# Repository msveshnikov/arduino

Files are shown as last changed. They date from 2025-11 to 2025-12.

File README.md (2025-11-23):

# First hyper-interactive Robot based on Google Robotics models/gemini-robotics-er-1.5-preview

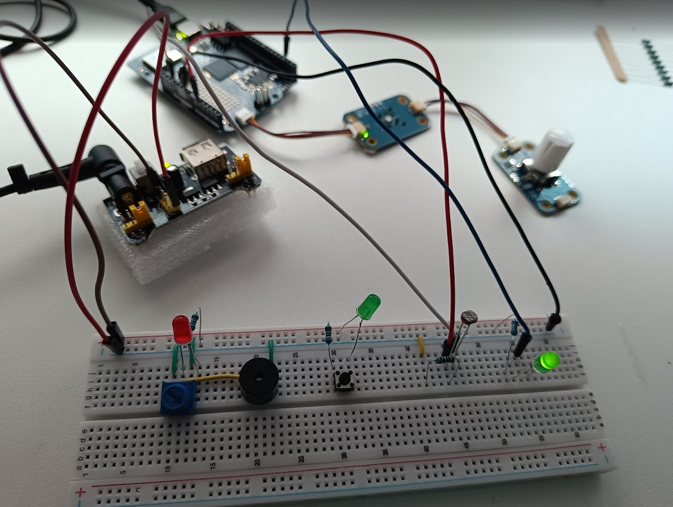
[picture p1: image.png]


## Overview

This project aims to create a highly interactive, autonomous robot utilizing the Google Gemini Robotics ER 1.5 Preview API for decision-making and real-time interaction.

## Current Prototype Specifications

-   **Core Hardware:** Arduino Uno Q (Microcontroller/Motor Control)
-   **Movement:** Two wheels with 360-degree movement capability (differential drive) - **Pins 5 (Left) & 6 (Right)**
-   **Peripherals:** USB-C dongle (USB Camera, USB Speaker, Microphone)
-   **Sensors:** Proximity/Distance Sensor (Analog Pin A0)
-   **Power:** PowerBank 20000 mAh
-   **Software Stack:** Python 3.12, Google Gemini Robotics ER 1.5 Preview API
-   **Connectivity:** WiFi required for API access

**Functionality:** Uses wheels for movement, microphone for audio input, speaker for audio output, and camera for visual input. Capable of making autonomous decisions driven by the AI model.

---

## Design Ideas and Future Considerations

### 1. Hardware Enhancements and Modularity

| Area | Current Status | Proposed Enhancement | Rationale |
| :--- | :--- | :--- | :--- |
| **Microcontroller** | Arduino Uno Q | Transition to Raspberry Pi (e.g., Pi 5 or Zero 2 W) or equivalent SBC | Offload Python processing, improve camera/audio stream handling, and provide local processing capability. |
| **Motor Control** | Integrated with Uno Q | Dedicated Motor Driver Shield (e.g., L298N or specialized drivers) | Better current handling, precision control, and separation of logic/power circuits. |
| **Sensing/Navigation** | USB Camera only | Integrate IMU (Accelerometer/Gyroscope) and Proximity Sensors (Ultrasonic/LiDAR) | Enable robust spatial awareness, obstacle avoidance, and precise movement/pose tracking. |
| **Physical Structure** | N/A (Assumed generic) | Custom 3D Printed Chassis | Modular housing for components, better stability, and improved aesthetics for component housing. |
| **Power Management** | Single PowerBank | Integrated Power Distribution Board (PDB) with voltage regulation | Ensure stable power for SBC, motors, and peripherals; implement low-power warning system. |

### 2. Software Architecture and Code Structure

The project currently uses foundational C code (`music.c`, `starwars.c`, `temp.c`) for low-level tasks, while `main.py` handles high-level logic and API interaction.

-   **Refactor C Code:** Consolidate low-level hardware interaction (motor control, sensor reading) into a dedicated library (e.g., `hardware_interface.c`) callable by Python via `ctypes` or similar bindings.
-   **Python Logic (`main.py`):**
    -   Implement a clear state machine for autonomous behavior (e.g., Idle, Exploring, Interacting, Charging).
    -   Separate API communication handling (API client) from local decision-making (Behavior Tree).
-   **Configuration Management:** Introduce a `config.json` or environment variables for API keys, WiFi settings, and hardware calibration values.

### 3. Interaction and Autonomy Features

-   **Actuation:** Introduce one manipulator arm (e.g., 2-3 DOF) for basic physical object interaction, manipulation, and demonstration.
-   **Multi-Modal Interaction:** Beyond simple command/response, implement context memory for longer, more meaningful conversations that persist across interactions.
-   **Environmental Mapping:** Integrate Simultaneous Localization and Mapping (SLAM) capabilities (if transitioning to an SBC) to allow the robot to navigate and remember its environment structure.
-   **Task Execution:** Design a robust system for handling complex, multi-step instructions (e.g., "Go to the kitchen and report if the coffee machine is on").

### 4. Project Development Setup

-   **Dependency Management:** Utilize a `requirements.txt` file for explicit Python dependency tracking.
-   **Development Environment:** Expand the `.vscode/settings.json` to include linting (e.g., Black, Pylint) and debugging configurations for easier collaboration and development setup.

# Robot Hardware Schema

## Overview

The robot consists of an MCU (Arduino) handling motor control and an MPU (PC/SBC) handling high-level logic, vision, and audio. They are connected via USB (Serial).

## Connection Diagram

```mermaid
graph TD
    subgraph MPU ["MPU (Computer/SBC)"]
        Python[Python Script]
        Webcam[USB Webcam]
        Mic[USB Microphone]
        Speaker[USB Speaker]

        Python <--> Webcam
        Python <--> Mic
        Python <--> Speaker
    end

    subgraph MCU ["MCU (Arduino)"]
        Bridge[Arduino_RouterBridge]
        ServoL["Servo Left (Pin 5)"]
        ServoR["Servo Right (Pin 6)"]
        Sensor["Proximity Sensor (Pin A0)"]

        Bridge --> ServoL
        Bridge --> ServoR
        Bridge --> Sensor
    end

    Python <-->|USB Serial 115200 baud| Bridge
```

## Pinout Configuration

| Component | Arduino Pin | Description |
| :--- | :--- | :--- |
| **Servo Left**  | D5 | Left Wheel (Continuous Rotation)  |
| **Servo Right** | D6 | Right Wheel (Continuous Rotation) |
| **Sensor** | A0 | Proximity/Distance Analog Input |
| **USB** | USB Port | Serial Communication with MPU |

## Power Distribution

-   **Arduino**: Powered via USB or external 7-12V DC jack.
-   **Servos**: **CRITICAL**: Do NOT power servos directly from the Arduino 5V pin. Use an external 5V power supply (e.g., 4xAA battery pack or 5V/2A adapter) for the servos. Connect the external power ground to Arduino GND.

## MPU Requirements

-   **OS**: Linux Debian
-   **Python**: 3.12+
-   **Ports**: 1x USB for Arduino, 1x USB for Webcam, 1x USB for Audio (or 3.5mm jacks).

# TODO

-   [x] use only two motors (servos), reverse one for turning left right
-   [x] get pic from USB and send it to LLM model
-   [x] in prompt ask for json output with fixed schema, allowing speaking and moving (we have no head or arms)
-   [x] speak loudly if returned by model
-   [x] listen to mic and send transcription to LLM model with USB cam picture and proximity sensor data

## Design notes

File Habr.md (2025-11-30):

# Как я собрал робота с характером на базе Gemini API и Arduino Uno Q (и научил его подмигивать)

Привет, Хабр!

Вы когда-нибудь мечтали о роботе, который не просто выполняет команды «едь прямо» или «поверни налево», а может обидеться на вас за глупый вопрос или радостно подмигнуть, увидев кота? Я тоже. И решил, что хватит мечтать — пора собирать.

В этой статье я расскажу, как за пару вечеров собрал "гипер-интерактивного" робота, используя **Arduino Uno Q**, немного Python-магии и **Google Gemini Robotics API**. У него нет рук, нет ног, но есть колеса, матричное лицо и, самое главное, — характер.

<cut/>

## Идея: "Мозг" и "Мышцы"

Главная проблема DIY-роботов — вычислительная мощность. Обычно приходится выбирать между Arduino (хорошо крутит моторами) и Raspberry Pi (умеет думать). Но **Arduino Uno Q** меняет правила игры. Она объединяет в себе и то, и другое:

1.  **MPU (Main Processing Unit)**: Мощный "мозг" на Python, который видит, слышит и общается с LLM (Large Language Model).
2.  **MCU (Microcontroller Unit)**: "Мышцы" (C++), которые дергают сервоприводами, светят светодиодами и следят за датчиками.

## Железо: Из чего же сделаны наши мальчишки?

Сборка получилась максимально доступной (ну, почти):

-   **Arduino Uno Q **: Звезда шоу. Встроенная LED-матрица 12x8 — это киллер-фича для создания "лица" робота без лишних проводов.
-   **Шасси**: Классическая двухколесная платформа (differential drive).
-   **Сервоприводы**: 2 штуки постоянного вращения (Continuous Rotation).
-   **Глаза**: 2 красных светодиода (потому что робот должен выглядеть немного зловеще, правда?). Подключены к пинам 2 и 3.
-   **Сенсоры**: Аналоговый датчик расстояния (чтобы не врезаться в стены, пока мечтает о захвате мира).
-   **Периферия**: USB-вебкамера, микрофон и колонка (подключены к "мозгу").

Схема подключения проста как пробка:

```mermaid
graph TD
    subgraph Arduino Uno Q
        MPU[Python MPU] <-->|Internal Serial| MCU[Arduino MCU]
    end
    MCU --> LeftMotor[Левый мотор D5]
    MCU --> RightMotor[Правый мотор D6]
    MCU --> Eyes[Глаза D2, D3]
    MCU --> Matrix[Матрица 12x8]
```

## Софт: Оживляем Франкенштейна

### 1. Arduino (C++)

Код для микроконтроллера занимается тем, что парсит команды от Python и управляет железом. Самое интересное тут — это **эмоции**.

Благодаря библиотеке `Arduino_LED_Matrix`, мы можем рисовать на встроенной матрице R4. Я определил несколько "кадров" для эмоций:

-   Neutral (Спокойствие)
-   Happy (Счастье)
-   Sad (Грусть)
-   Angry (Гнев — любимая эмоция моего робота)
-   Surprised (Удивление)

Команда от Python приходит в формате: `L90;R90;E1;Y11`.

-   `L/R`: Скорость моторов (90 — стоп).
-   `E`: ID эмоции.
-   `Y`: Состояние глаз (11 — оба горят, 10 — левый горит, и т.д.).

### 2. Python (MPU)

Этот код выполняется на MPU части платы. Мы используем **Google Gemini Robotics ER 1.5 Preview**. Это не просто чат-бот, это мультимодальная модель, которая может "видеть" картинки и понимать контекст.

Самое важное — это **System Prompt**. Мы должны объяснить модели, кто она такая и как управлять своим телом.

```python
self.system_prompt = """
You are a robot assistant with two wheels and NO arms.
You have an LED matrix for a face and two extra LEDs for eyes.
You must respond in valid JSON format ONLY.
The JSON schema is:
{
    "speech": "text to speak",
    "left_motor": int (-100 to 100),
    "right_motor": int (-100 to 100),
    "emotion": "neutral" | "happy" | "sad" | "angry" | "surprised",
    "eyes": {"left": bool, "right": bool}
}
"""
```

Заметьте, мы не пишем `if text == "hello": smile()`. Мы даем модели **полную свободу**. Если она решит, что ваша шутка смешная, она вернет `emotion: "happy"`. Если вы ее оскорбите — `emotion: "angry"` и, возможно, `left_motor: 100` (таранный удар).

## Как это работает в жизни

Цикл работы робота выглядит так:

1.  **Слушаем**: Распознаем речь через `speech_recognition`.
2.  **Смотрим**: Делаем снимок с веб-камеры.
3.  **Думаем**: Отправляем текст + картинку + данные сенсоров в Gemini.
4.  **Действуем**: Получаем JSON, парсим его и шлем команды на Arduino.
5.  **Говорим**: Озвучиваем ответ через `pyttsx3`.

### Пример диалога:

**Я**: "Привет! Как настроение?"
**Робот** (JSON от Gemini):

```json
{
    "speech": "Привет! Системы в норме, настроение боевое.",
    "emotion": "happy",
    "eyes": { "left": true, "right": true },
    "left_motor": 0,
    "right_motor": 0
}
```

_На матрице загорается смайлик, глаза светятся._

**Я**: "Помигай глазами!"
**Робот**:

```json
{
    "speech": "Пожалуйста. Бип-буп.",
    "emotion": "neutral",
    "eyes": {"left": false, "right": true},
    ...
}
```

_Один глаз гаснет, робот подмигивает._

## Грабли, на которые я наступил

1.  **Питание сервоприводов**: Никогда, слышите, НИКОГДА не питайте моторы от 5V пина Arduino. Я поплатился часами отладки "почему оно перезагружается при повороте". Только внешнее питание!
2.  **JSON Hallucinations**: Иногда LLM забывает закрыть скобку или добавляет лишний текст. Пришлось добавить `try-except` и очистку от markdown-тегов.
3.  **Задержки**: Обработка картинки и запрос к API занимают время (1-2 секунды). Для real-time гонок не пойдет, но для вдумчивого собеседника — вполне.

## Итоги

Проект получился живым. Это не просто машинка на радиоуправлении, это сущность, которая _понимает_, что происходит вокруг. Добавление эмоций через LED-матрицу и глаза кардинально меняет восприятие устройства. Оно кажется... живым?

**Что дальше?**

-   Добавление манипулятора (руки!), чтобы он мог не только смотреть, но и трогать.
-   SLAM навигация.

Код проекта открыт (ну, лежит у меня в папке), так что дерзайте! Роботы — это весело. Особенно когда они умеют злиться.

---

_P.S. Если робот начнет просить коды запуска ядерных ракет, я его отключу. Обещаю._

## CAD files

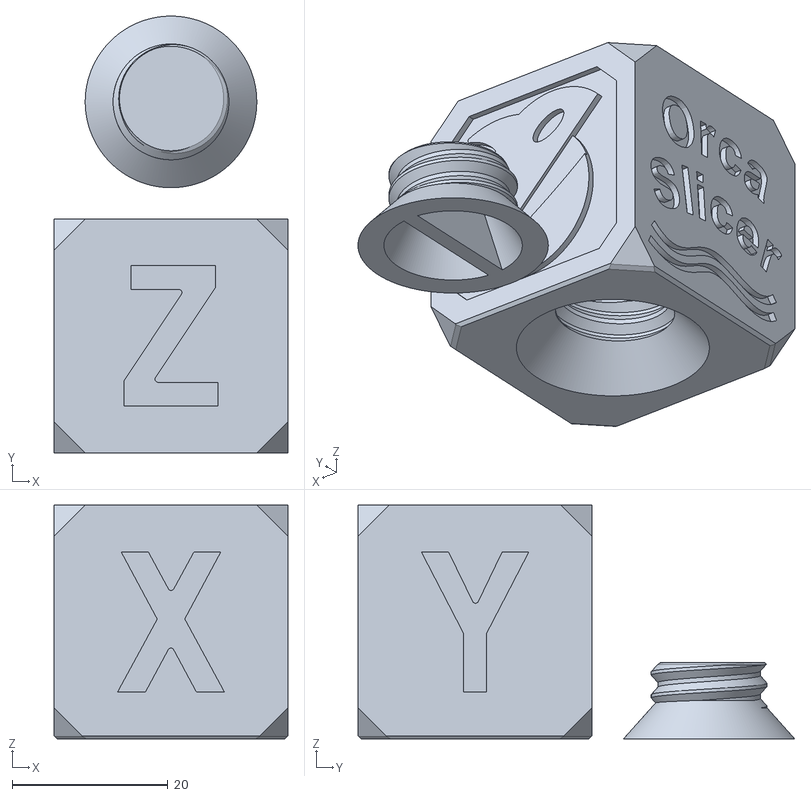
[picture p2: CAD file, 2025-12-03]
3d/OrcaCube.stl
30.0 x 56.0 x 30.0

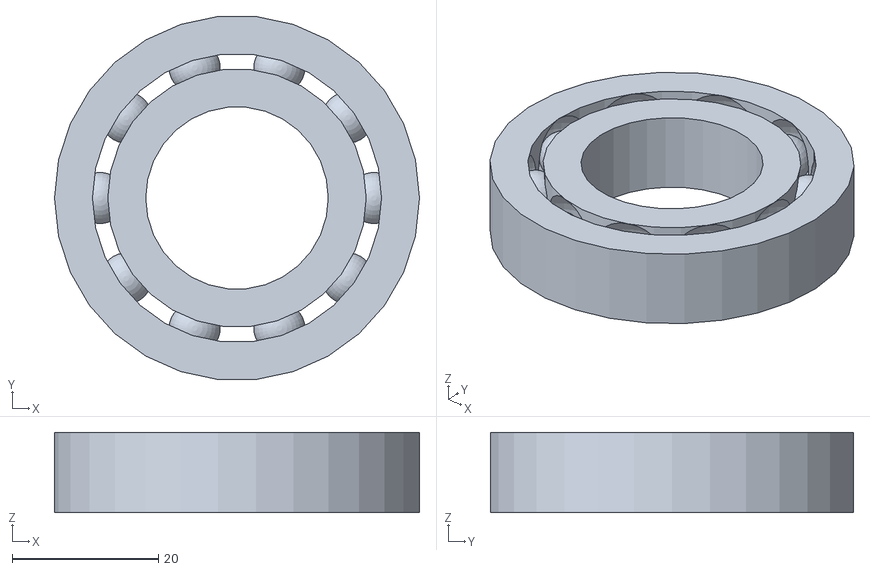
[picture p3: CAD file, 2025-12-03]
3d/bearing.stl
50.0 x 49.7 x 11.0

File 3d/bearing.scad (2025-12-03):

// Title: Подшипник (Print-in-Place Bearing)
// Description: Параметрическая модель шарикового подшипника, предназначенная для 3D-печати как единое целое.
// Author: AI Assistant
// Date: 2023-10-28
// License: MIT

/*
 * =====================================================================
 * Параметры для настройки (Parameters for Customization)
 * =====================================================================
 */

// --- Основные размеры ---
outer_diameter = 50;   // [mm] Внешний диаметр подшипника
inner_diameter = 25;   // [mm] Внутренний диаметр подшипника
height = 11;         // [mm] Высота подшипника

// --- Параметры шариков ---
num_balls = 10;      // Количество шариков
ball_diameter = 7;   // [mm] Диаметр одного шарика

// --- Параметры для печати ---
clearance = 2.1;     // [mm] Зазор между деталями для свободного вращения
$fn = 30;             // Качество модели (количество граней), уменьшено по вашему запросу

/*
 * =====================================================================
 * Модули (Modules)
 * =====================================================================
 */

// Модуль для создания подшипника
module bearing() {
    // Вычисляем радиус, на котором будут располагаться шарики
    path_radius = (outer_diameter + inner_diameter) / 4;

    // Основное тело подшипника в сборе
    union() {
        // Создаем кольца с вырезами под шарики и зазором между собой
        difference() {
            // --- 1. Создаем исходное цельное кольцо ---
            difference() {
                cylinder(d = outer_diameter, h = height, center = true);
                cylinder(d = inner_diameter, h = height + 1, center = true);
            }

            // --- 2. Вырезаем тонкую щель для разделения колец ---
            // Эта операция создает зазор, превращая одно кольцо в два.
            difference() {
                cylinder(d = (path_radius * 2) + clearance, h = height + 1, center = true);
                cylinder(d = (path_radius * 2) - clearance, h = height + 2, center = true);
            }

            // --- 3. Вырезы для шариков (с зазором) ---
            // Делаем вырезы немного больше шариков, чтобы они могли вращаться.
            for (i = [0 : num_balls - 1]) {
                rotate([0, 0, i * 360 / num_balls]) {
                    translate([path_radius, 0, 0]) {
                        sphere(d = ball_diameter + clearance * 2);
                    }
                }
            }
        }

        // --- 4. Создаем сами шарики ---
        // Шарики размещаются в созданных для них полостях.
        for (i = [0 : num_balls - 1]) {
            rotate([0, 0, i * 360 / num_balls]) {
                translate([path_radius, 0, 0]) {
                    sphere(d = ball_diameter);
                }
            }
        }
    }
}

/*
 * =====================================================================
 * Основной код (Main Code)
 * =====================================================================
 */

bearing();

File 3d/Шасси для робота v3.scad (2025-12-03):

// Title: Robot Assembly (Chassis + 4 Wheels)
// Description: Parametric chassis with 4 wheels positioned 2mm outward.
// Combined and Modified by: AI Assistant

/*
 * =====================================================================
 * 1. GLOBAL PARAMETERS (Merged)
 * =====================================================================
 */

// --- Chassis Dimensions ---
chassis_length = 240;  // [mm] Y-axis
chassis_width = 120;   // [mm] X-axis
chassis_height = 40;   // [mm] Z-axis
wall_thickness = 3;    // [mm]

// --- Servo Cutouts ---
servo_cutout_width = 24;
servo_cutout_height = 12;
servo_hole_distance = 28;
servo_hole_diameter = 1.5;
servo_pos_from_front = 50; // Distance from servo center to front

// --- Rear Axle Holes ---
rear_hole_diameter = 6;
rear_hole_pos_from_back = 40;

// --- Vertical Positioning ---
cutouts_z_pos = 20; // Height of axles/servos

// --- Chassis Posts ---
post_size = 10;
post_height = 5;

// --- Wheel Parameters ---
wheel_diameter = 60;
wheel_thickness = 5;
wheel_offset = 2; // [mm] Distance from chassis wall to wheel

// --- Tread Parameters ---
tread_grooves = 40;
tread_groove_depth = 1.5;
tread_groove_width = 4;

// --- Wheel Mounting Parameters ---
mount_hole_distance = 32;
mount_hole_diameter = 1.5;
servo_horn_recess_depth = 2.5;
servo_spline_hole_diameter = 6;
servo_horn_hub_diameter = 7;
servo_horn_arm_width = 6;

// --- Quality ---
$fn = 100;

/*
 * =====================================================================
 * 2. MODULE: CHASSIS
 * =====================================================================
 */
module make_chassis() {
    
    // Sub-module for body
    module chassis_body_shape() {
        difference() {
            cube([chassis_width, chassis_length, chassis_height]);
            translate([wall_thickness, wall_thickness, wall_thickness]) {
                cube([
                    chassis_width - 2 * wall_thickness, 
                    chassis_length - 2 * wall_thickness, 
                    chassis_height
                ]);
            }
        }
    }

    // Sub-module for posts
    module mounting_posts() {
        translate([0, 0, chassis_height])
            cube([post_size, post_size, post_height]);
        translate([chassis_width - post_size, 0, chassis_height])
            cube([post_size, post_size, post_height]);
        translate([0, chassis_length - post_size, chassis_height])
            cube([post_size, post_size, post_height]);
        translate([chassis_width - post_size, chassis_length - post_size, chassis_height])
            cube([post_size, post_size, post_height]);
    }

    difference() {
        union() {
            chassis_body_shape();
            mounting_posts();
        }
        
        y_center_servo = chassis_length - servo_pos_from_front;
        z_center = cutouts_z_pos;
        
        // --- Left Servo ---
        translate([-1, y_center_servo - servo_cutout_width/2, z_center - servo_cutout_height/2])
            cube([wall_thickness + 2, servo_cutout_width, servo_cutout_height]);
        translate([wall_thickness/2, y_center_servo - servo_hole_distance/2, z_center])
            rotate([0, 90, 0]) cylinder(d=servo_hole_diameter, h=wall_thickness*3, center=true);
        translate([wall_thickness/2, y_center_servo + servo_hole_distance/2, z_center])
            rotate([0, 90, 0]) cylinder(d=servo_hole_diameter, h=wall_thickness*3, center=true);
        
        // --- Right Servo ---
        translate([chassis_width - wall_thickness, y_center_servo - servo_cutout_width/2, z_center - servo_cutout_height/2])
            cube([wall_thickness + 2, servo_cutout_width, servo_cutout_height]);
        translate([chassis_width - wall_thickness/2, y_center_servo - servo_hole_distance/2, z_center])
            rotate([0, 90, 0]) cylinder(d=servo_hole_diameter, h=wall_thickness*3, center=true);
        translate([chassis_width - wall_thickness/2, y_center_servo + servo_hole_distance/2, z_center])
            rotate([0, 90, 0]) cylinder(d=servo_hole_diameter, h=wall_thickness*3, center=true);
        
        // --- Rear Axles ---
        translate([-1, rear_hole_pos_from_back, cutouts_z_pos])
            rotate([0, 90, 0]) cylinder(d = rear_hole_diameter, h = wall_thickness + 2);
        translate([chassis_width - wall_thickness, rear_hole_pos_from_back, cutouts_z_pos])
            rotate([0, 90, 0]) cylinder(d = rear_hole_diameter, h = wall_thickness + 2);
    }
}

/*
 * =====================================================================
 * 3. MODULE: WHEEL
 * =====================================================================
 */
module make_wheel() {
    
    module wheel_base() {
        cylinder(d = wheel_diameter, h = wheel_thickness);
    }

    module tread_cutter() {
        if (tread_grooves > 0) {
            for (i = [0 : 360/tread_grooves : 359]) {
                rotate([0, 0, i]) {
                    translate([wheel_diameter/2 - tread_groove_depth, -tread_groove_width/2, -1]) {
                        cube([tread_groove_depth + 1, tread_groove_width, wheel_thickness + 2]);
                    }
                }
            }
        }
    }

    module servo_horn_cutout() {
        cutter_h = servo_horn_recess_depth + 1;
        translate([0, 0, wheel_thickness - servo_horn_recess_depth]) {
            hull() {
                cylinder(d = servo_horn_hub_diameter, h = cutter_h);
                translate([mount_hole_distance / 2, 0, 0])
                    cylinder(d = servo_horn_arm_width, h = cutter_h);
                translate([-mount_hole_distance / 2, 0, 0])
                    cylinder(d = servo_horn_arm_width, h = cutter_h);
            }
        }
    }

    module all_holes() {
        hole_h = wheel_thickness + 2;
        translate([0, 0, wheel_thickness / 2]) {
            cylinder(d = servo_spline_hole_diameter, h = hole_h, center = true);
            translate([mount_hole_distance / 2, 0, 0])
                cylinder(d = mount_hole_diameter, h = hole_h, center = true);
            translate([-mount_hole_distance / 2, 0, 0])
                cylinder(d = mount_hole_diameter, h = hole_h, center = true);
        }
    }

    difference() {
        wheel_base();
        tread_cutter();
        servo_horn_cutout();
        all_holes();
    }
}

/*
 * =====================================================================
 * 4. ASSEMBLY (Main Code)
 * =====================================================================
 */

// 1. Render the Chassis
color("green") 
    make_chassis();

// Calculated Y coordinates
y_front = chassis_length - servo_pos_from_front;
y_rear = rear_hole_pos_from_back;

// Calculated X coordinates for wheels (2mm gap)
// Left wheel origin: Gap (2mm) + Thickness (5mm) = 7mm from edge
x_left_wheel = 0 - wheel_offset - wheel_thickness; 
// Right wheel origin: Width + Gap (2mm) + Thickness (5mm)
x_right_wheel = chassis_width + wheel_offset + wheel_thickness; 

// 2. Render 4 Wheels
// Note: We rotate the wheels so the "Recess" (Servo horn side) faces the chassis.
// The recess is at the top of the cylinder (Z=thickness).

// Front Left
translate([x_left_wheel, y_front, cutouts_z_pos])
    rotate([0, 90, 0]) // Rotate 90 deg so top faces Right (towards chassis)
    color("White") make_wheel();

// Front Right
translate([x_right_wheel, y_front, cutouts_z_pos])
    rotate([0, -90, 0]) // Rotate -90 deg so top faces Left (towards chassis)
    color("White") make_wheel();

// Rear Left
translate([x_left_wheel, y_rear, cutouts_z_pos])
    rotate([0, 90, 0])
    color("White") make_wheel();

// Rear Right
translate([x_right_wheel, y_rear, cutouts_z_pos])
    rotate([0, -90, 0])
    color("White") make_wheel();

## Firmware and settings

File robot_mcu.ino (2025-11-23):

#include <Arduino_RouterBridge.h>
#include <Servo.h>

// Configuration
const int MAX_SERVOS = 2; // Left and Right wheels
const int LEFT_SERVO_PIN = 5;
const int RIGHT_SERVO_PIN = 6;
const int SENSOR_PIN = A0; // Placeholder for sensor

Servo leftServo;
Servo rightServo;

// Bridge function to set servo angle (Legacy support, though we mainly use L/R commands now)
void set_servo(int index, int angle) {
  angle = constrain(angle, 0, 180);
  if (index == 0) leftServo.write(angle);
  else if (index == 1) rightServo.write(angle);
  Bridge.returnResult(true);
}

void setup() {
  // Initialize Bridge
  Bridge.begin();
  
  // Attach servos
  leftServo.attach(LEFT_SERVO_PIN);
  rightServo.attach(RIGHT_SERVO_PIN);
  
  // Stop motors initially (90 is usually stop for continuous rotation servos)
  leftServo.write(90);
  rightServo.write(90);
  
  // Register Bridge functions
  Bridge.provide("set_servo", set_servo);
}

void loop() {
  // 1. Ask Python for commands
  String command;
  if (Bridge.call("tick").result(command)) {
    if (command != "NOOP" && command.length() > 0) {
      parseAndExecute(command);
    }
  }
  
  // 2. Read Sensors and send to Python
  int sensorValue = analogRead(SENSOR_PIN);
  // We can send this every loop or periodically. Let's do it every loop for now.
  Bridge.call("update_sensors", sensorValue);
  
  // Small delay
  delay(50);
}

void parseAndExecute(String cmdString) {
  // Format: "L<angle>;R<angle>" e.g. "L100;R80"
  
  int separator = cmdString.indexOf(';');
  if (separator > 0) {
    String leftCmd = cmdString.substring(0, separator);
    String rightCmd = cmdString.substring(separator + 1);
    
    if (leftCmd.startsWith("L")) {
      int angle = leftCmd.substring(1).toInt();
      leftServo.write(constrain(angle, 0, 180));
    }
    
    if (rightCmd.startsWith("R")) {
      int angle = rightCmd.substring(1).toInt();
      rightServo.write(constrain(angle, 0, 180));
    }
  } else {
      // Fallback for single commands if any
  }
}

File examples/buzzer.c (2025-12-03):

// the setup function runs once when you press reset or power the board
/*void setup() {
  // initialize digital pin LED_BUILTIN as an output.
  pinMode(LED_BUILTIN, OUTPUT);
  pinMode(3, OUTPUT);
  pinMode(9, OUTPUT);

}

// the loop function runs over and over again forever
void loop() {
  digitalWrite(3, HIGH);
  digitalWrite(LED_BUILTIN, HIGH);  // turn the LED on (HIGH is the voltage level)
  tone(9,300);
  delay(100);                      
  digitalWrite(3, LOW);
  digitalWrite(LED_BUILTIN, LOW);   // turn the LED off by making the voltage LOW
  tone(9,500);
  delay(100);                      
}
*/
/* 
  Imperial March - Star Wars
  Connect a piezo buzzer or speaker to pin 11 or select a new pin.
  More songs available at https://github.com/robsoncouto/arduino-songs                                            
                                              
                                              Robson Couto, 2019
*/

#define NOTE_B0  31
#define NOTE_C1  33
#define NOTE_CS1 35
#define NOTE_D1  37
#define NOTE_DS1 39
#define NOTE_E1  41
#define NOTE_F1  44
#define NOTE_FS1 46
#define NOTE_G1  49
#define NOTE_GS1 52
#define NOTE_A1  55
#define NOTE_AS1 58
#define NOTE_B1  62
#define NOTE_C2  65
#define NOTE_CS2 69
#define NOTE_D2  73
#define NOTE_DS2 78
#define NOTE_E2  82
#define NOTE_F2  87
#define NOTE_FS2 93
#define NOTE_G2  98
#define NOTE_GS2 104
#define NOTE_A2  110
#define NOTE_AS2 117
#define NOTE_B2  123
#define NOTE_C3  131
#define NOTE_CS3 139
#define NOTE_D3  147
#define NOTE_DS3 156
#define NOTE_E3  165
#define NOTE_F3  175
#define NOTE_FS3 185
#define NOTE_G3  196
#define NOTE_GS3 208
#define NOTE_A3  220
#define NOTE_AS3 233
#define NOTE_B3  247
#define NOTE_C4  262
#define NOTE_CS4 277
#define NOTE_D4  294
#define NOTE_DS4 311
#define NOTE_E4  330
#define NOTE_F4  349
#define NOTE_FS4 370
#define NOTE_G4  392
#define NOTE_GS4 415
#define NOTE_A4  440
#define NOTE_AS4 466
#define NOTE_B4  494
#define NOTE_C5  523
#define NOTE_CS5 554
#define NOTE_D5  587
#define NOTE_DS5 622
#define NOTE_E5  659
#define NOTE_F5  698
#define NOTE_FS5 740
#define NOTE_G5  784
#define NOTE_GS5 831
#define NOTE_A5  880
#define NOTE_AS5 932
#define NOTE_B5  988
#define NOTE_C6  1047
#define NOTE_CS6 1109
#define NOTE_D6  1175
#define NOTE_DS6 1245
#define NOTE_E6  1319
#define NOTE_F6  1397
#define NOTE_FS6 1480
#define NOTE_G6  1568
#define NOTE_GS6 1661
#define NOTE_A6  1760
#define NOTE_AS6 1865
#define NOTE_B6  1976
#define NOTE_C7  2093
#define NOTE_CS7 2217
#define NOTE_D7  2349
#define NOTE_DS7 2489
#define NOTE_E7  2637
#define NOTE_F7  2794
#define NOTE_FS7 2960
#define NOTE_G7  3136
#define NOTE_GS7 3322
#define NOTE_A7  3520
#define NOTE_AS7 3729
#define NOTE_B7  3951
#define NOTE_C8  4186
#define NOTE_CS8 4435
#define NOTE_D8  4699
#define NOTE_DS8 4978
#define REST      0


// change this to make the song slower or faster
int tempo = 120;

// change this to whichever pin you want to use
int buzzer = 9;

// notes of the moledy followed by the duration.
// a 4 means a quarter note, 8 an eighteenth , 16 sixteenth, so on
// !!negative numbers are used to represent dotted notes,
// so -4 means a dotted quarter note, that is, a quarter plus an eighteenth!!
int melody[] = {
  
  // Dart Vader theme (Imperial March) - Star wars 
  // Score available at https://musescore.com/user/202909/scores/1141521
  // The tenor saxophone part was used
  
  NOTE_A4,-4, NOTE_A4,-4, NOTE_A4,16, NOTE_A4,16, NOTE_A4,16, NOTE_A4,16, NOTE_F4,8, REST,8,
  NOTE_A4,-4, NOTE_A4,-4, NOTE_A4,16, NOTE_A4,16, NOTE_A4,16, NOTE_A4,16, NOTE_F4,8, REST,8,
  NOTE_A4,4, NOTE_A4,4, NOTE_A4,4, NOTE_F4,-8, NOTE_C5,16,

  NOTE_A4,4, NOTE_F4,-8, NOTE_C5,16, NOTE_A4,2,//4
  NOTE_E5,4, NOTE_E5,4, NOTE_E5,4, NOTE_F5,-8, NOTE_C5,16,
  NOTE_A4,4, NOTE_F4,-8, NOTE_C5,16, NOTE_A4,2,
  
  NOTE_A5,4, NOTE_A4,-8, NOTE_A4,16, NOTE_A5,4, NOTE_GS5,-8, NOTE_G5,16, //7 
  NOTE_DS5,16, NOTE_D5,16, NOTE_DS5,8, REST,8, NOTE_A4,8, NOTE_DS5,4, NOTE_D5,-8, NOTE_CS5,16,

  NOTE_C5,16, NOTE_B4,16, NOTE_C5,16, REST,8, NOTE_F4,8, NOTE_GS4,4, NOTE_F4,-8, NOTE_A4,-16,//9
  NOTE_C5,4, NOTE_A4,-8, NOTE_C5,16, NOTE_E5,2,

  NOTE_A5,4, NOTE_A4,-8, NOTE_A4,16, NOTE_A5,4, NOTE_GS5,-8, NOTE_G5,16, //7 
  NOTE_DS5,16, NOTE_D5,16, NOTE_DS5,8, REST,8, NOTE_A4,8, NOTE_DS5,4, NOTE_D5,-8, NOTE_CS5,16,

  NOTE_C5,16, NOTE_B4,16, NOTE_C5,16, REST,8, NOTE_F4,8, NOTE_GS4,4, NOTE_F4,-8, NOTE_A4,-16,//9
  NOTE_A4,4, NOTE_F4,-8, NOTE_C5,16, NOTE_A4,2,
  
};

// sizeof gives the number of bytes, each int value is composed of two bytes (16 bits)
// there are two values per note (pitch and duration), so for each note there are four bytes
int notes = sizeof(melody) / sizeof(melody[0]) / 2;

// this calculates the duration of a whole note in ms
int wholenote = (60000 * 4) / tempo;

int divider = 0, noteDuration = 0;

void setup() {
  // iterate over the notes of the melody. 
  // Remember, the array is twice the number of notes (notes + durations)
  for (int thisNote = 0; thisNote < notes * 2; thisNote = thisNote + 2) {

    // calculates the duration of each note
    divider = melody[thisNote + 1];
    if (divider > 0) {
      // regular note, just proceed
      noteDuration = (wholenote) / divider;
    } else if (divider < 0) {
      // dotted notes are represented with negative durations!!
      noteDuration = (wholenote) / abs(divider);
      noteDuration *= 1.5; // increases the duration in half for dotted notes
    }

    // we only play the note for 90% of the duration, leaving 10% as a pause
    tone(buzzer, melody[thisNote], noteDuration*0.9);

    // Wait for the specief duration before playing the next note.
    delay(noteDuration);
    
    // stop the waveform generation before the next note.
    noTone(buzzer);
  }
}

void loop() {
  // no need to repeat the melody.
}
